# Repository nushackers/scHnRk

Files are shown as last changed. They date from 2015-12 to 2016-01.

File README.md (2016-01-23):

# scHnRk

The scHnRk (pronounced as snark) is a digispark/arduino compatible prototyping board developed for Hack&Roll'16.

The hardware design, firmware and software are derived from Galvant/usb_wrapper-pcb, digispark, micronucleus and arduino. Any derivative from their work is released under the Creative Commons License CC BY 4.0 wherever possible. (I'm no lawyer)

## Hardware

This design is adapted from the venerable DigiSpark.

Here's the lowdown on the stats
- ATTINY85
  - 8KB Flash Memory
  - 512B EEPROM
  - 6 I/O Pins (SPI)
- Acessories
  - 5 WS2812B LEDs
  - 2 CR2032 Battery Holders
  - 2 LEDs (Status, Pwr)
  - USB Wrapper (In some circles its called USB Condom)
  - USB Connector

The scHnRk consists of 2 independent components, separable from one another. The main componenet is a digispark clone which is fully assembled, the smaller component is a partially assembled/ unassembled usb-wrapper-pcb kit. 

## Kits

### Green (unassembled usb-wrapper-pcb)

- Resistor Information for green kits can be inferred from the following  
  - Galvant/usb_wrapper-pcb (Github)
    - Most basic configuration => R7 == 75K Ohm, R9 == 43.2K Ohm, R8 == R10 == 49.9K Ohm
    - R4 == 180 Ohm, LED == LED

### Orange (partially assembled usb-wrapper-pcb)

- Just solder on USB connector and you're set!

## Firmware

A jig will be provided on the day itself for firmware (bootloader) reprogramming using SPI. 

## Software

Feel free to program your arduino anyway you want during the competition using arduino IDE and the "on board" USB port!

## Designed by

```
NUSHackers and Pals

Chang Chu-Ming
Chinmay Pendharkar
Harish Venkatesan
Kenneth Lim
Vishnu Prem
Rahul Gokul
Sayanee Basu
Shanmugam Mpl
Yeo Kheng Meng
Jeremias Wong
```

## Secret Features

One has to be granted WOC REPUS Previleges before one accesses the secret features/puzzle.

There might be prizes for people who crack the puzzle during the hackathon! Maybe we forgot lol?

## Sponsors
 
### Platinum Sponsor
```
Zalora
```

### Gold Sponsors
```
Garena
Palantir
```

### Silver Sponsors
```
Titansoft
Google
Jane Street
Stripe
```

### Bronze Sponsors
```
Zopim
Carousell
NUS School of Computing
```

We thank the sponsors for making this happen.

Also we're looking out for sponsors for the next hackathon! Please contact us at coreteam@nushackers.org!

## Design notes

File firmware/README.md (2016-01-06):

# Firmware

## Hardware Setup

Here's our hardware setup to load the firmware into the ScHnRk.

- Windows Computer
  - AVRISP (USB)
    - AVRISP (SPI)
      - Self made jig
        - ScHnRk SPI interface 

We used microneucleus bootloader for schnrk v0.1 - v0.7

### Archived Setup

Raspberry Pi bit banging seems to fail, so we are using AVRISP instead.

```
Raspberry Pi
- GPIO pin to push NO (Normally Open) button, pulled up to high
- I2C
  - PCF8574 port expander
    -HD44780 LCD Controller
      -*LCD*
- SPI
  - Self made jig
    - ScHnRk SPI interface 
```

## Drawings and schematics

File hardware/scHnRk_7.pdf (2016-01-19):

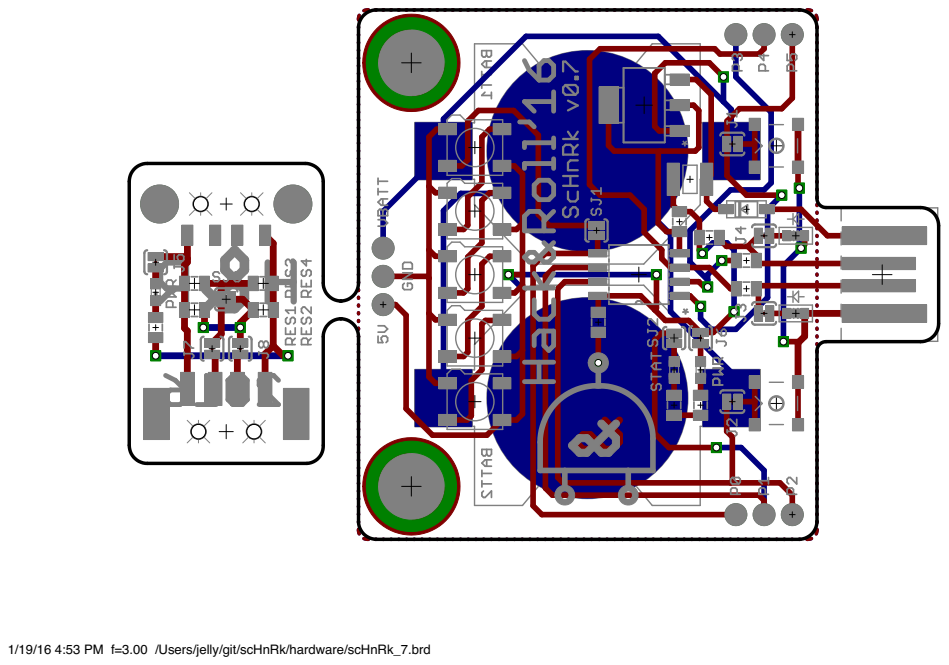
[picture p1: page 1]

1/19/16 4:53 PM f=3.00 /Users/jelly/git/scHnRk/hardware/scHnRk_7.brd

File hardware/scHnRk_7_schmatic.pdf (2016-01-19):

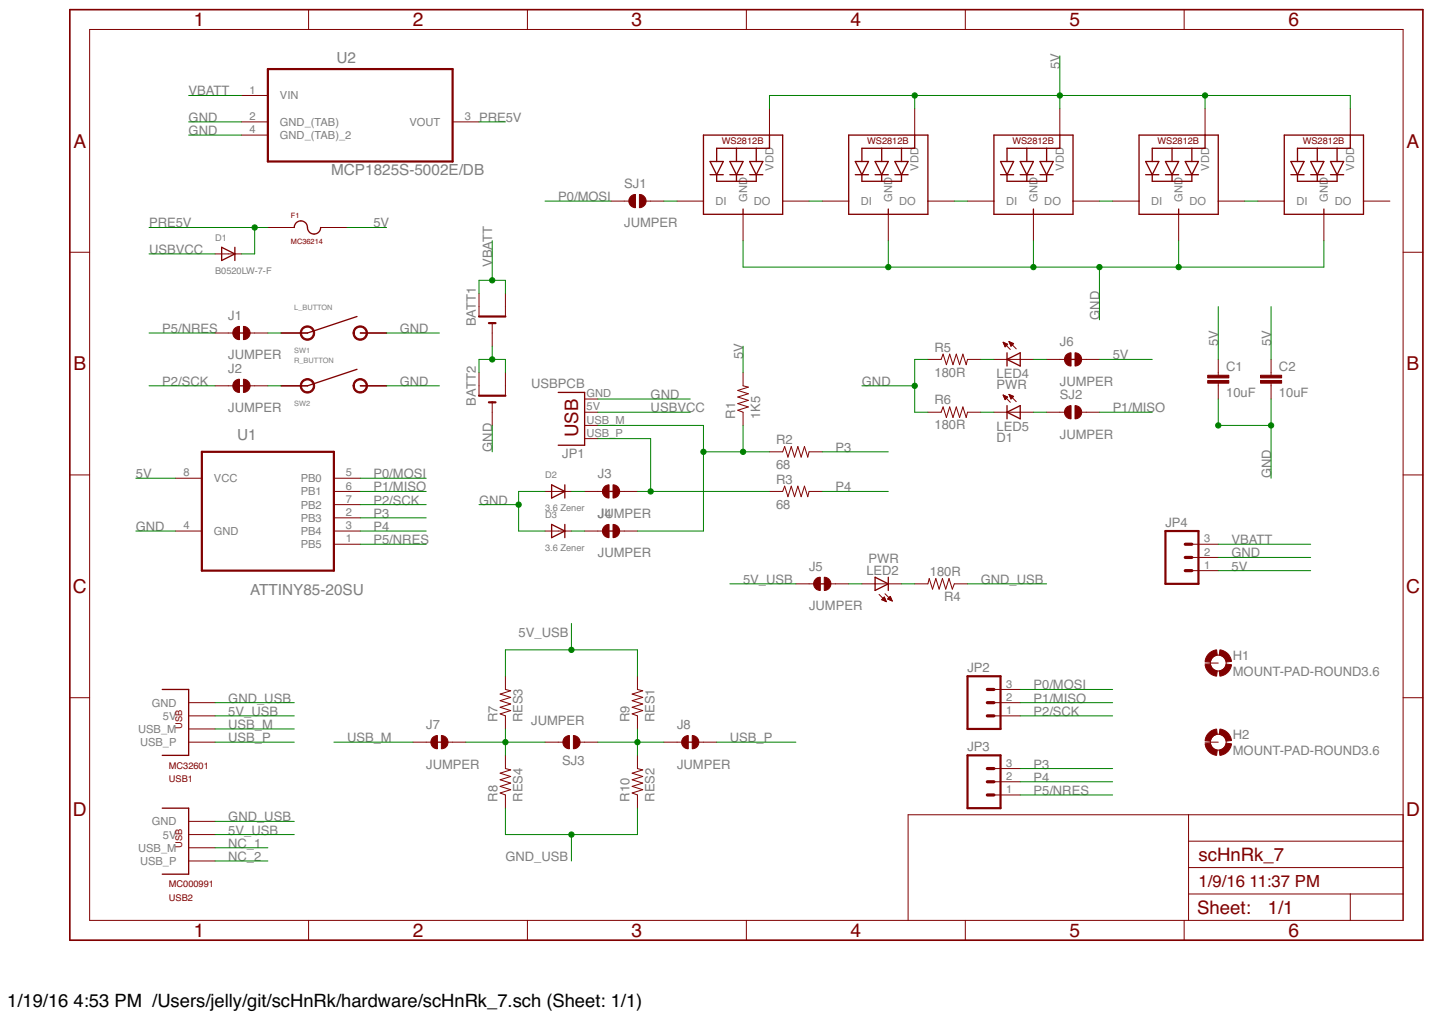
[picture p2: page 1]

1/19/16 4:53 PM /Users/jelly/git/scHnRk/hardware/scHnRk_7.sch (Sheet: 1/1)

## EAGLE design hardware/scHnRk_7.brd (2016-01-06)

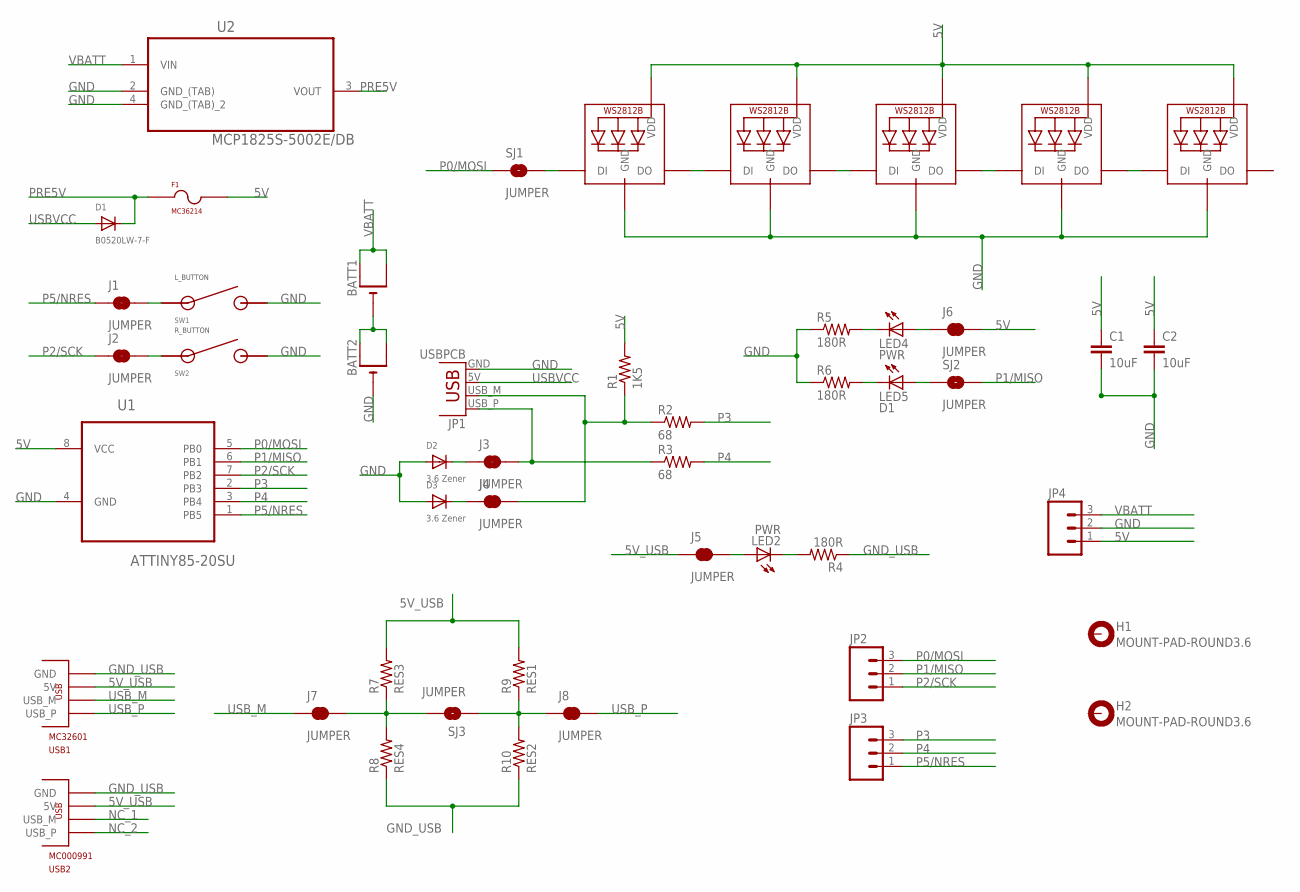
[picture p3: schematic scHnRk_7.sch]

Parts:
BATT1, BATT2: CR2032SMT; CR2032-SMD
C1, C2: 10uF; 0805
D1: B0520LW-7-F; SOD-123
D2, D3: 3.6 Zener; SOD-523
F1: MC36214
H1, H2: MOUNT-PAD-ROUND3.6; 3,6-PAD
J1, J2, J3, J4, J5, J6, J7, J8: JUMPER; PAD-JUMPER-2-NC_BY_TRACE_YES_SILK
JP1: USBPCB; USB-A-PCB
JP2, JP3, JP4: M031X03_NO_SILK; 1X03_NO_SILK
LED1, LED3, LED6, LED7, LED8: WS2812B5050; WS2812B
LED2, LED4: PWR; CHIPLED_0603
LED5: D1; CHIPLED_0603
R1: 1K5; 0805
R2, R3: 68; 0805
R4, R5, R6: 180R; 0805
R7: RES3; 0805
R8: RES4; 0805
R9: RES1; 0805
R10: RES2; 0805
SJ1, SJ2, SJ3: JUMPER; PAD-JUMPER-2-NO_YES_SILK
SW1: L_BUTTON; SKRBAGE010
SW2: R_BUTTON; SKRBAGE010
U1: ATTINY85-20SU; SOIC127P798X216-8N
U2: MCP1825S-5002E/DB; SOT230P700X180-4N
USB1: MC32601
USB2: MC000991

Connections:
5V: C1.1, C2.1, F1.P$2, J6.2, JP4.1, LED1.1-VDD (VDD), LED3.1-VDD (VDD), LED6.1-VDD (VDD), LED7.1-VDD (VDD), LED8.1-VDD (VDD), R1.2, U1.8 (VCC)
5V_USB: J5.1, R7.2, R9.2, USB1.P$2 (5V), USB2.P$4 (5V)
GND: BATT2.-, C1.2, C2.2, D2.A, D3.A, JP1.GND, JP4.2, LED1.3-GND (GND), LED3.3-GND (GND), LED6.3-GND (GND), LED7.3-GND (GND), LED8.3-GND (GND), R5.1, R6.1, SW1.P$2, SW1.P$4, SW2.P$2, SW2.P$4, U1.4 (GND), U2.2 (GND_(TAB)), U2.4 (GND_(TAB)_2)
GND_USB: R4.1, R8.1, R10.1, USB1.P$5 (GND), USB2.P$1 (GND)
unnamed: BATT1.-, BATT2.+$1 (+), BATT2.+$2 (+1)
unnamed: J1.2, SW1.P$1, SW1.P$3
unnamed: LED1.2-DOUT (DO), LED3.4-DIN (DI)
unnamed: LED3.2-DOUT (DO), LED6.4-DIN (DI)
unnamed: LED6.2-DOUT (DO), LED7.4-DIN (DI)
unnamed: LED7.2-DOUT (DO), LED8.4-DIN (DI)
unnamed: J5.2, LED2.A
unnamed: J2.2, SW2.P$1, SW2.P$3
unnamed: D2.K (C), J3.1
unnamed: D3.K (C), J4.1
unnamed: LED1.4-DIN (DI), SJ1.2
unnamed: J4.2, JP1.USB_M (D-), R1.1, R2.1
unnamed: J3.2, JP1.USB_P (D+), R3.1
unnamed: J7.2, R7.1, R8.2, SJ3.2
unnamed: J8.1, R9.1, R10.2, SJ3.1
unnamed: LED2.C, R4.2
unnamed: LED4.C, R5.2
unnamed: LED5.C, R6.2
unnamed: J6.1, LED4.A
unnamed: LED5.A, SJ2.1
NC_1: USB2.P$3 (USB_M)
NC_2: USB2.P$2 (USB_P)
P0/MOSI: JP2.3, SJ1.1, U1.5 (PB0)
P1/MISO: JP2.2, SJ2.2, U1.6 (PB1)
P2/SCK: J2.1, JP2.1, U1.7 (PB2)
P3: JP3.3, R2.2, U1.2 (PB3)
P4: JP3.2, R3.2, U1.3 (PB4)
P5/NRES: J1.1, JP3.1, U1.1 (PB5)
PRE5V: D1.C, F1.P$1, U2.3 (VOUT)
USBVCC: D1.A, JP1.5V (VBUS)
USB_M: J7.1, USB1.P$3 (USB_M)
USB_P: J8.2, USB1.P$4 (USB_P)
VBATT: BATT1.+$1 (+), BATT1.+$2 (+1), JP4.3, U2.1 (VIN)

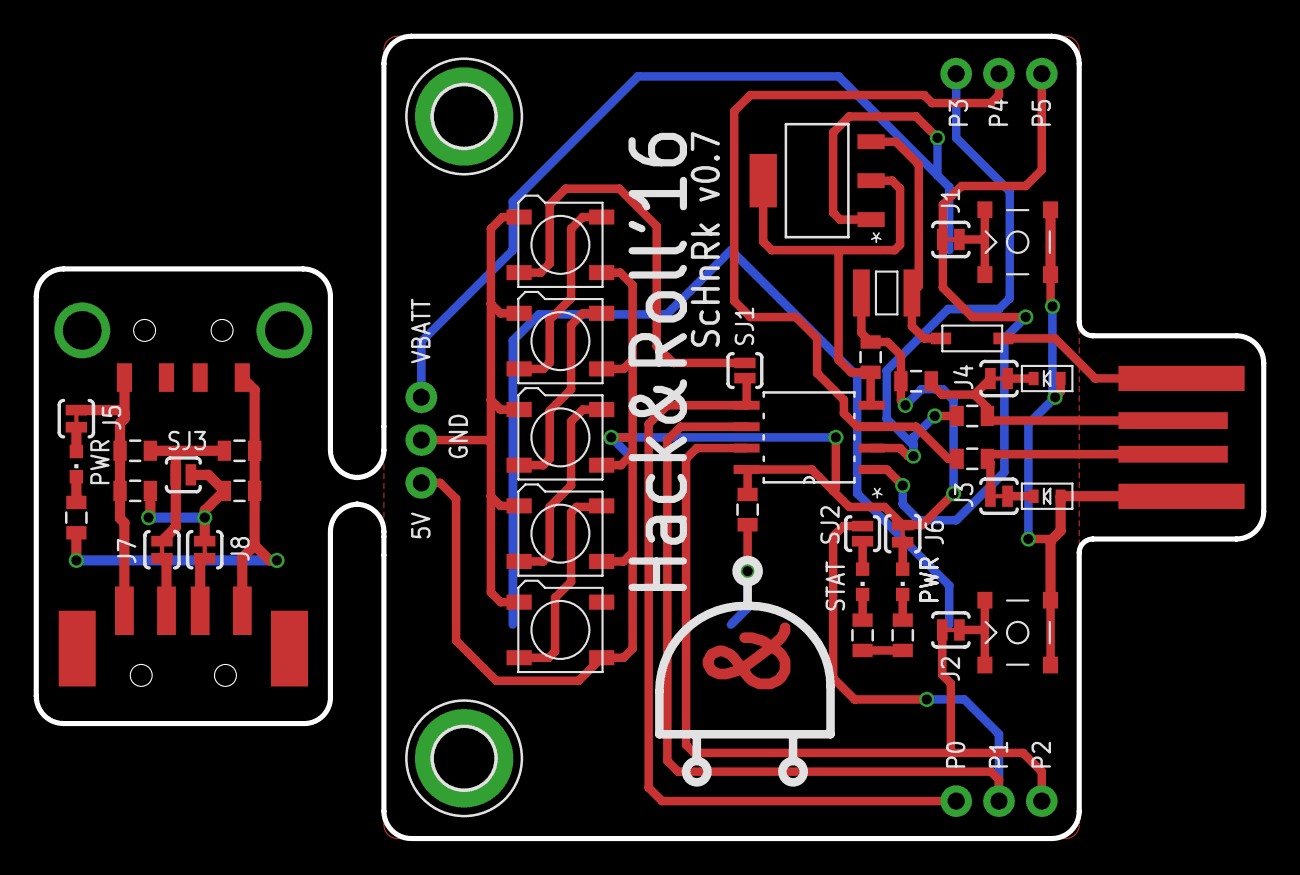
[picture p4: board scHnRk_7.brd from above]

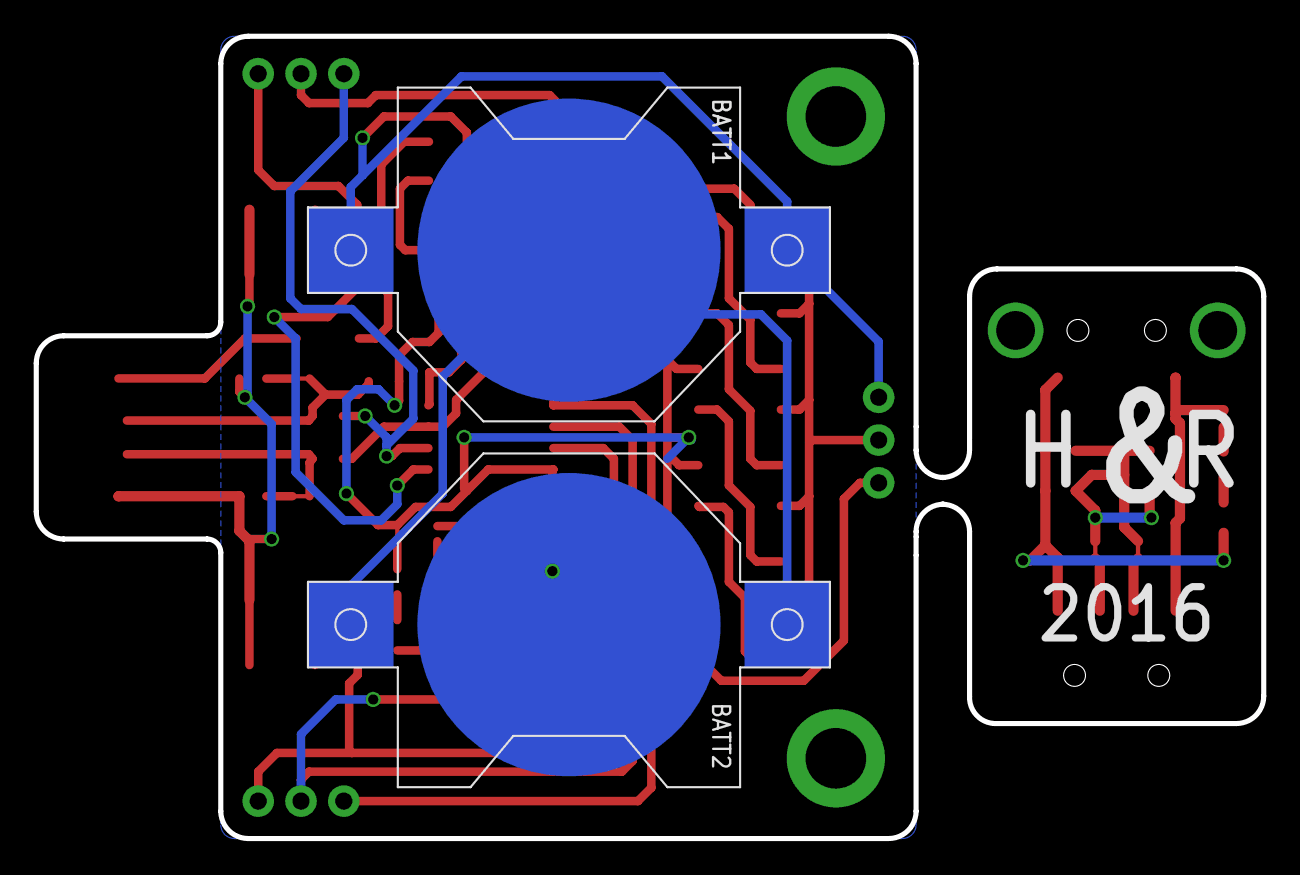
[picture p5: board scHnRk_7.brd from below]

Board: 2 copper layers, 72.9 x 47.6 mm, 49 parts (2 on the bottom side), 35 nets.

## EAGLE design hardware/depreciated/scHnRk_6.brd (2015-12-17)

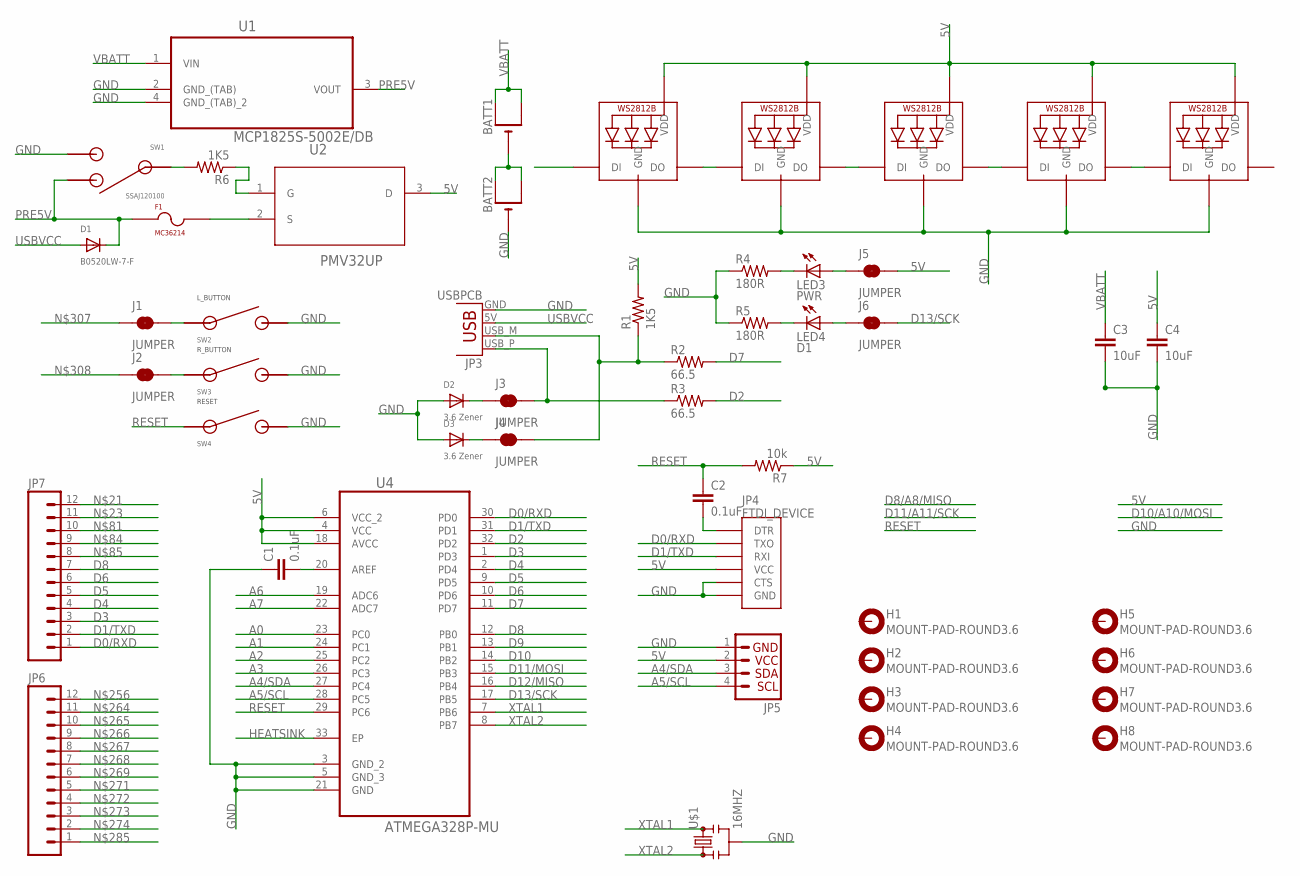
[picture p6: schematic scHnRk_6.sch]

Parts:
BATT1, BATT2: CR2032SMT; CR2032-SMD
C1, C2: 0.1uF; 0805
C3, C4: 10uF; 0805
D1: B0520LW-7-F; SOD-123
D2, D3: 3.6 Zener; SOD-523
F1: MC36214
H1, H2, H3, H4, H5, H6, H7, H8: MOUNT-PAD-ROUND3.6; 3,6-PAD
J1, J2, J3, J4, J5, J6: JUMPER; PAD-JUMPER-2-NC_BY_TRACE_YES_SILK
JP3: USBPCB; USB-A-PCB
JP4: FTDI_DEVICE; FTDI_DEVICE_SIDE
JP5: I2C_STANDARD; 1X04
JP6, JP7: M12PTH; 1X12
LED1, LED2, LED5, LED6, LED7: WS2812B5050; WS2812B
LED3: PWR; CHIPLED_0603
LED4: D1; CHIPLED_0603
R1, R6: 1K5; 0805
R2, R3: 66.5; 0603-RES
R4, R5: 180R; 0805
R7: 10k; 0805
SW1: SSAJ120100
SW2: L_BUTTON; SKRBAGE010
SW3: R_BUTTON; SKRBAGE010
SW4: RESET; SKRBAGE010
U1: MCP1825S-5002E/DB; SOT230P700X180-4N
U2: PMV32UP; SOT95P230X110-3N
U4: ATMEGA328P-MU; QFN50P500X500X100-33N
U$1: 16MHZ; RESONATOR-SMD

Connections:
5V: C4.1, J5.2, JP4.P$4 (VCC), JP5.2, LED1.1-VDD (VDD), LED2.1-VDD (VDD), LED5.1-VDD (VDD), LED6.1-VDD (VDD), LED7.1-VDD (VDD), R1.2, R7.1, U2.3 (D), U4.4 (VCC), U4.6 (VCC_2), U4.18 (AVCC)
A0: U4.23 (PC0)
A1: U4.24 (PC1)
A2: U4.25 (PC2)
A3: U4.26 (PC3)
A4/SDA: JP5.3, U4.27 (PC4)
A5/SCL: JP5.4, U4.28 (PC5)
A6: U4.19 (ADC6)
A7: U4.22 (ADC7)
D0/RXD: JP4.P$2 (TXO), JP7.1, U4.30 (PD0)
D1/TXD: JP4.P$3 (RXI), JP7.2, U4.31 (PD1)
D2: R3.2, U4.32 (PD2)
D3: JP7.3, U4.1 (PD3)
D4: JP7.4, U4.2 (PD4)
D5: JP7.5, U4.9 (PD5)
D6: JP7.6, U4.10 (PD6)
D7: R2.2, U4.11 (PD7)
D8: JP7.7, U4.12 (PB0)
D9: U4.13 (PB1)
D10: U4.14 (PB2)
D11/MOSI: U4.15 (PB3)
D12/MISO: U4.16 (PB4)
D13/SCK: J6.2, U4.17 (PB5)
GND: BATT2.-, C1.1, C3.2, C4.2, D2.A, D3.A, JP3.GND, JP4.P$5 (CTS), JP4.P$6 (GND), JP5.1, LED1.3-GND (GND), LED2.3-GND (GND), LED5.3-GND (GND), LED6.3-GND (GND), LED7.3-GND (GND), R4.1, R5.1, SW1.P$2, SW2.P$2, SW2.P$4, SW3.P$2, SW3.P$4, SW4.P$2, SW4.P$4, U1.2 (GND_(TAB)), U1.4 (GND_(TAB)_2), U4.3 (GND_2), U4.5 (GND_3), U4.21 (GND), U$1.2
HEATSINK: U4.33 (EP)
unnamed: BATT1.-, BATT2.+$1 (+), BATT2.+$2 (+1)
unnamed: J1.2, SW2.P$1, SW2.P$3
unnamed: LED1.2-DOUT (DO), LED2.4-DIN (DI)
unnamed: LED2.2-DOUT (DO), LED5.4-DIN (DI)
unnamed: LED5.2-DOUT (DO), LED6.4-DIN (DI)
unnamed: LED6.2-DOUT (DO), LED7.4-DIN (DI)
unnamed: R6.2, SW1.P$C
unnamed: J2.2, SW3.P$1, SW3.P$3
unnamed: D2.K (C), J3.1
unnamed: D3.K (C), J4.1
unnamed: J4.2, JP3.USB_M (D-), R1.1, R2.1
unnamed: J3.2, JP3.USB_P (D+), R3.1
unnamed: R6.1, U2.1 (G)
unnamed: F1.P$2, U2.2 (S)
unnamed: C2.2, JP4.P$1 (DTR)
unnamed: LED3.C, R4.2
unnamed: LED4.C, R5.2
unnamed: J5.1, LED3.A
unnamed: J6.1, LED4.A
unnamed: C1.2, U4.20 (AREF)
PRE5V: D1.C, F1.P$1, SW1.P$1, U1.3 (VOUT)
RESET: C2.1, R7.2, SW4.P$1, SW4.P$3, U4.29 (PC6)
USBVCC: D1.A, JP3.5V (VBUS)
VBATT: BATT1.+$1 (+), BATT1.+$2 (+1), C3.1, U1.1 (VIN)
XTAL1: U4.7 (PB6), U$1.3
XTAL2: U4.8 (PB7), U$1.1

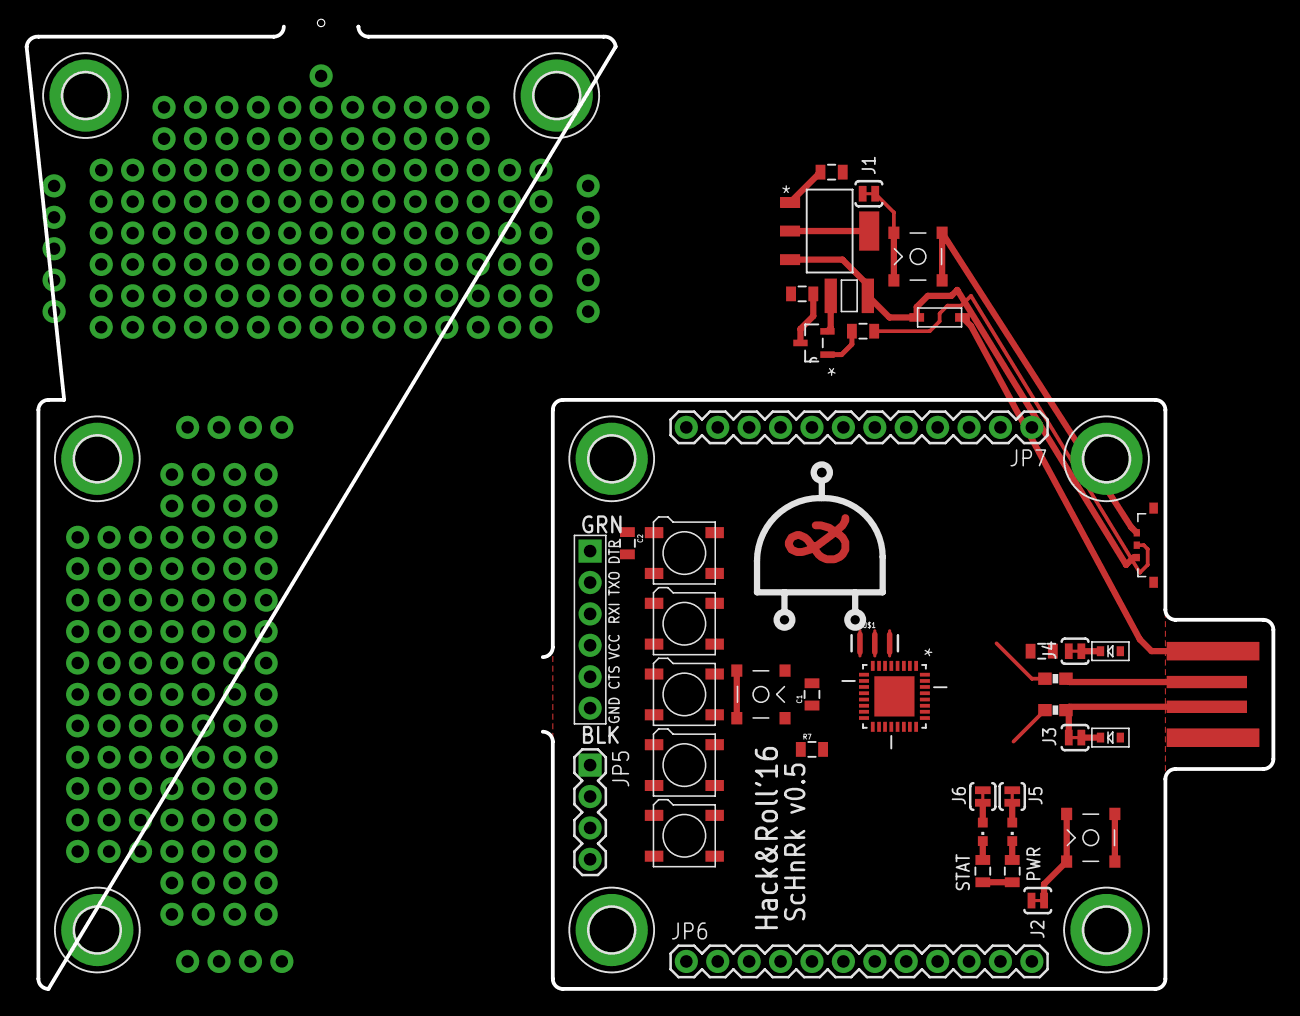
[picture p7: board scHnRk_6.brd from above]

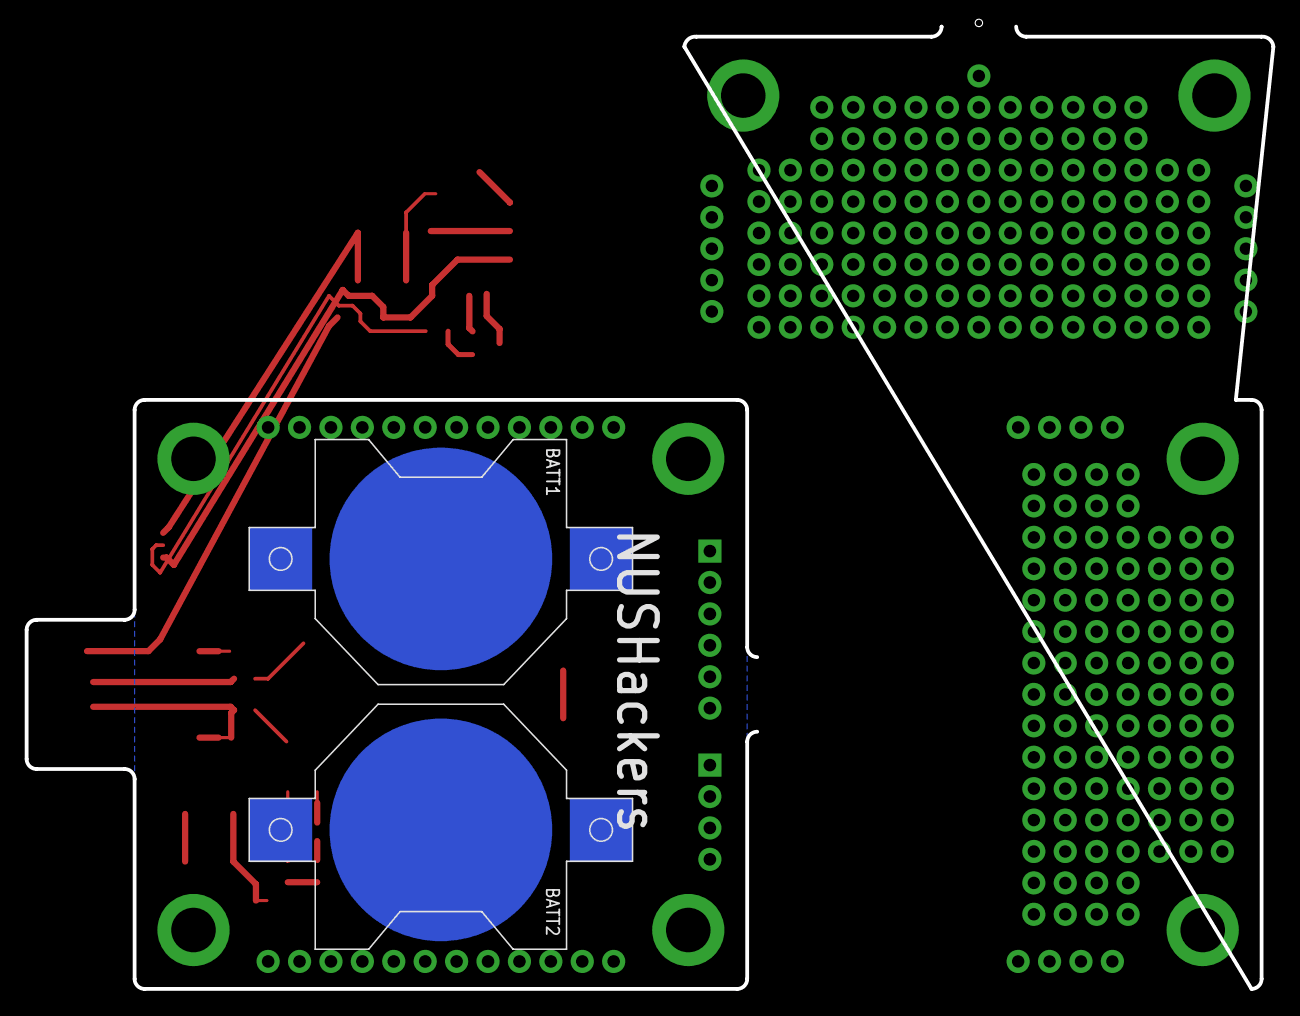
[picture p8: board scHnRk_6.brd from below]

Board: 2 copper layers, 100.8 x 77.8 mm, 51 parts (2 on the bottom side), 40 nets.

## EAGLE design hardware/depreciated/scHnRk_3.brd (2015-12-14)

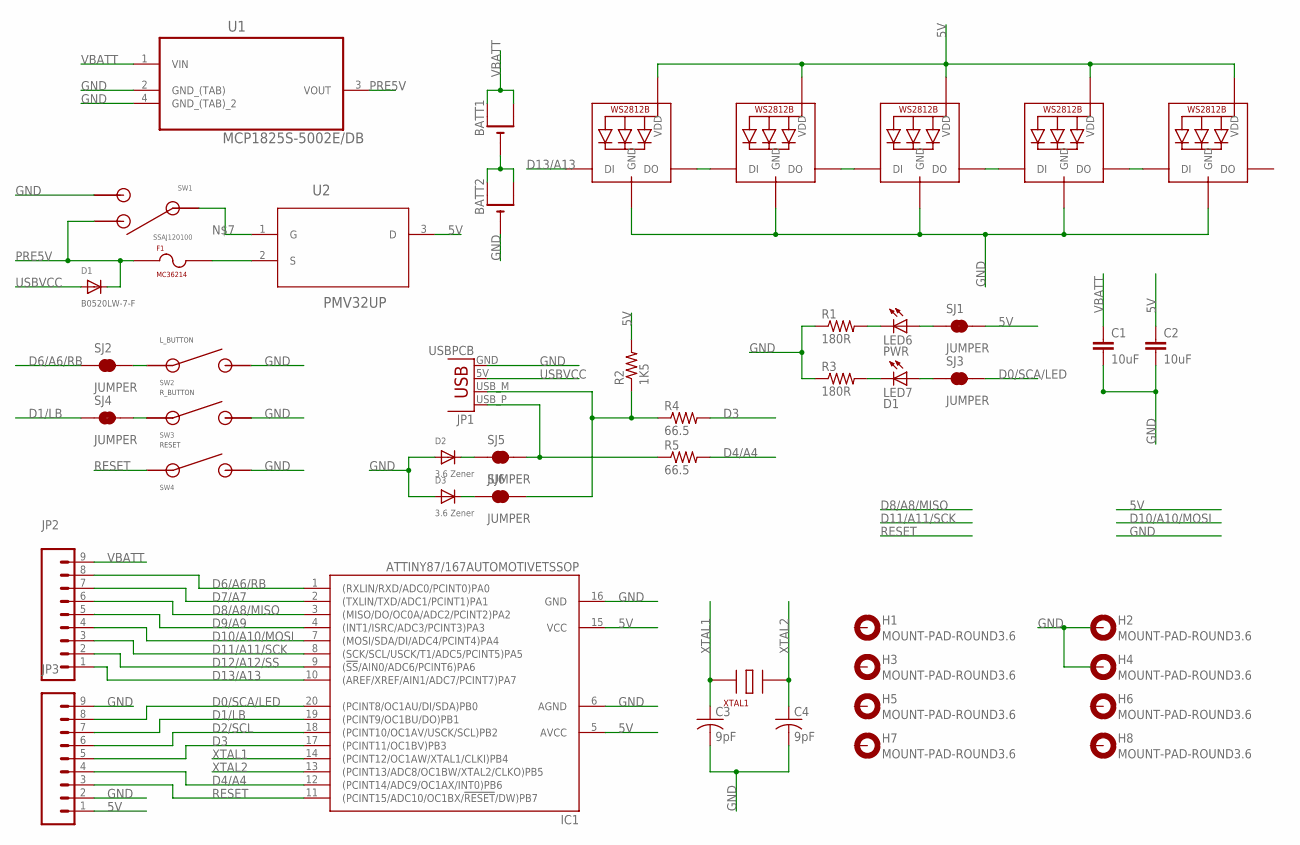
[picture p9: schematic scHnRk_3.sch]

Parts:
BATT1, BATT2: CR2032SMT; CR2032-SMD
C1, C2: 10uF; 0805
C3, C4: 9pF; C0603K
D1: B0520LW-7-F; SOD-123
D2, D3: 3.6 Zener; SOD-523
F1: MC36214
H1, H2, H3, H4, H5, H6, H7, H8: MOUNT-PAD-ROUND3.6; 3,6-PAD
IC1: ATTINY87/167AUTOMOTIVETSSOP; TSSOP20
JP1: USBPCB; USB-A-PCB
JP2, JP3: M09; 1X09
LED1, LED2, LED3, LED4, LED5: WS2812B5050; WS2812B
LED6: PWR; CHIPLED_0603
LED7: D1; CHIPLED_0603
R1, R3: 180R; R0603
R2: 1K5; R0603
R4, R5: 66.5; R0603
SJ1, SJ2, SJ3, SJ4, SJ5, SJ6: JUMPER; PAD-JUMPER-2-NC_BY_TRACE_YES_SILK
SW1: SSAJ120100
SW2: L_BUTTON; SKRBAGE010
SW3: R_BUTTON; SKRBAGE010
SW4: RESET; SKRBAGE010
U1: MCP1825S-5002E/DB; SOT230P700X180-4N
U2: PMV32UP; SOT95P230X110-3N
XTAL1: 16MHZ-2467444

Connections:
5V: C2.1, IC1.5 (AVCC), IC1.15 (VCC), JP3.1, LED1.1-VDD (VDD), LED2.1-VDD (VDD), LED3.1-VDD (VDD), LED4.1-VDD (VDD), LED5.1-VDD (VDD), R2.2, SJ1.2, U2.3 (D)
D0/SCA/LED: IC1.20 ((PCINT8/OC1AU/DI/SDA)PB0), JP3.8, SJ3.2
D1/LB: IC1.19 ((PCINT9/OC1BU/DO)PB1), JP3.7, SJ4.1
D2/SCL: IC1.18 ((PCINT10/OC1AV/USCK/SCL)PB2), JP3.6
D3: IC1.17 ((PCINT11/OC1BV)PB3), JP3.5, R4.2
D4/A4: IC1.12 ((PCINT14/ADC9/OC1AX/INT0)PB6), JP3.4, R5.2
D6/A6/RB: IC1.1 ((RXLIN/RXD/ADC0/PCINT0)PA0), JP2.8, SJ2.1
D7/A7: IC1.2 ((TXLIN/TXD/ADC1/PCINT1)PA1), JP2.7
D8/A8/MISO: IC1.3 ((MISO/DO/OC0A/ADC2/PCINT2)PA2), JP2.6
D9/A9: IC1.4 ((INT1/ISRC/ADC3/PCINT3)PA3), JP2.5
D10/A10/MOSI: IC1.7 ((MOSI/SDA/DI/ADC4/PCINT4)PA4), JP2.4
D11/A11/SCK: IC1.8 ((SCK/SCL/USCK/T1/ADC5/PCINT5)PA5), JP2.3
D12/A12/SS: IC1.9 ((!SS!/AIN0/ADC6/PCINT6)PA6), JP2.2
D13/A13: IC1.10 ((AREF/XREF/AIN1/ADC7/PCINT7)PA7), JP2.1, LED1.4-DIN (DI)
GND: BATT2.-, C1.2, C2.2, C3.2, C4.2, D2.A, D3.A, H2.B3,6, H4.B3,6, IC1.6 (AGND), IC1.16 (GND), JP1.GND, JP3.2, JP3.9, LED1.3-GND (GND), LED2.3-GND (GND), LED3.3-GND (GND), LED4.3-GND (GND), LED5.3-GND (GND), R1.1, R3.1, SW1.P$2, SW2.P$2, SW2.P$4, SW3.P$2, SW3.P$4, SW4.P$2, SW4.P$4, U1.2 (GND_(TAB)), U1.4 (GND_(TAB)_2)
unnamed: BATT1.-, BATT2.+$1 (+), BATT2.+$2 (+1)
unnamed: SJ2.2, SW2.P$1, SW2.P$3
unnamed: LED1.2-DOUT (DO), LED2.4-DIN (DI)
unnamed: LED2.2-DOUT (DO), LED3.4-DIN (DI)
unnamed: LED3.2-DOUT (DO), LED4.4-DIN (DI)
unnamed: LED4.2-DOUT (DO), LED5.4-DIN (DI)
unnamed: SW1.P$C, U2.1 (G)
unnamed: SJ4.2, SW3.P$1, SW3.P$3
unnamed: D2.K (C), SJ5.1
unnamed: D3.K (C), SJ6.1
unnamed: JP1.USB_M (D-), R2.1, R4.1, SJ6.2
unnamed: JP1.USB_P (D+), R5.1, SJ5.2
unnamed: F1.P$2, U2.2 (S)
unnamed: LED6.C, R1.2
unnamed: LED7.C, R3.2
unnamed: LED6.A, SJ1.1
unnamed: LED7.A, SJ3.1
PRE5V: D1.C, F1.P$1, SW1.P$1, U1.3 (VOUT)
RESET: IC1.11 ((PCINT15/ADC10/OC1BX/!RESET!/DW)PB7), JP3.3, SW4.P$1, SW4.P$3
USBVCC: D1.A, JP1.5V (VBUS)
VBATT: BATT1.+$1 (+), BATT1.+$2 (+1), C1.1, JP2.9, U1.1 (VIN)
XTAL1: C3.1, IC1.14 ((PCINT12/OC1AW/XTAL1/CLKI)PB4), XTAL1.P$1
XTAL2: C4.1, IC1.13 ((PCINT13/ADC8/OC1BW/XTAL2/CLKO)PB5), XTAL1.P$3

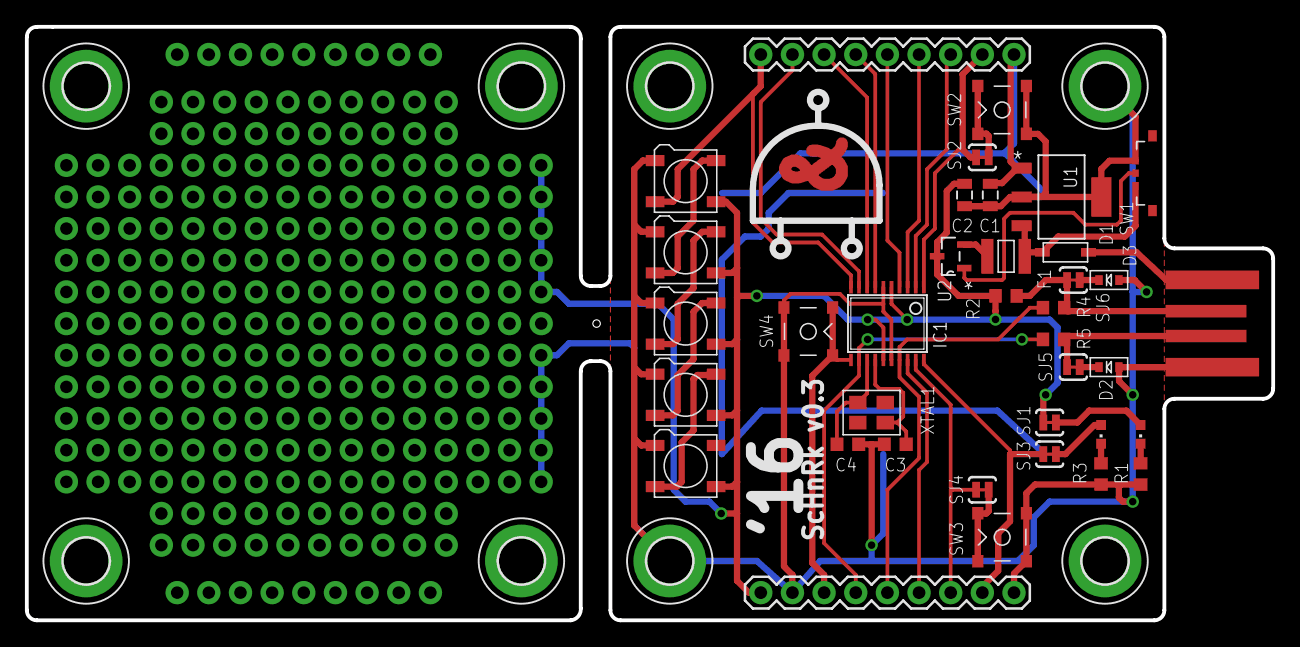
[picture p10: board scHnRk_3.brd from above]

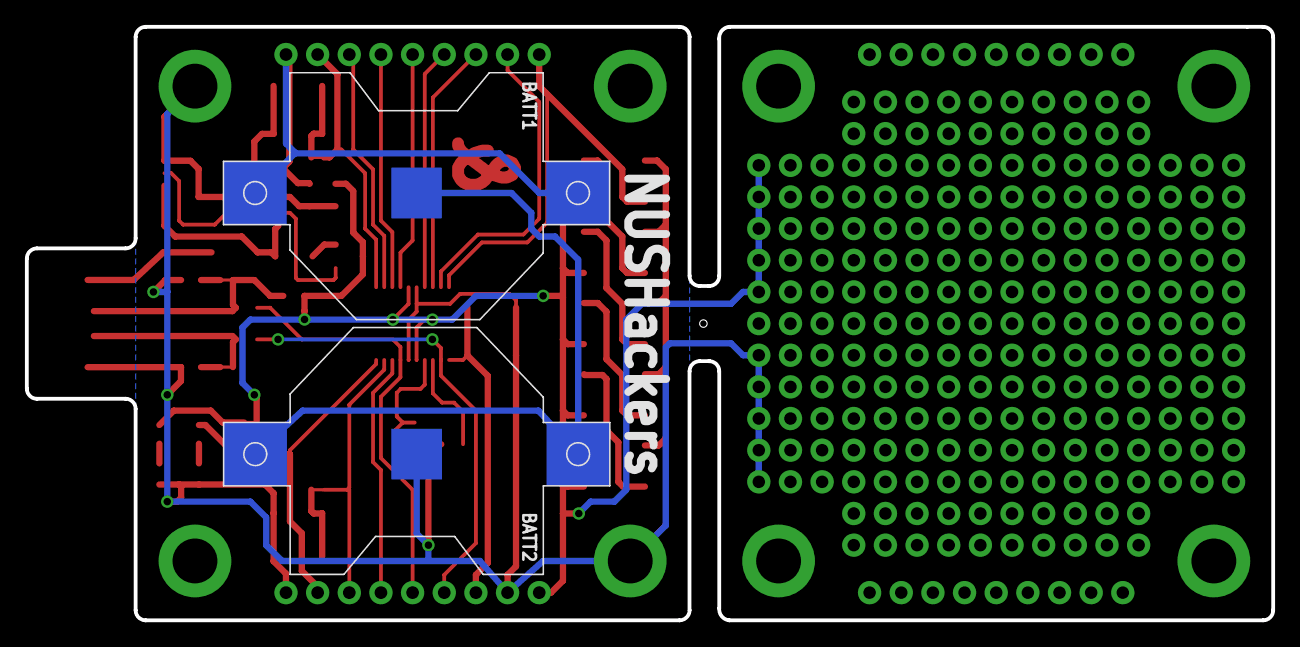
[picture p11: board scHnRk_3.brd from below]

Board: 2 copper layers, 100.0 x 47.6 mm, 47 parts (2 on the bottom side), 38 nets.

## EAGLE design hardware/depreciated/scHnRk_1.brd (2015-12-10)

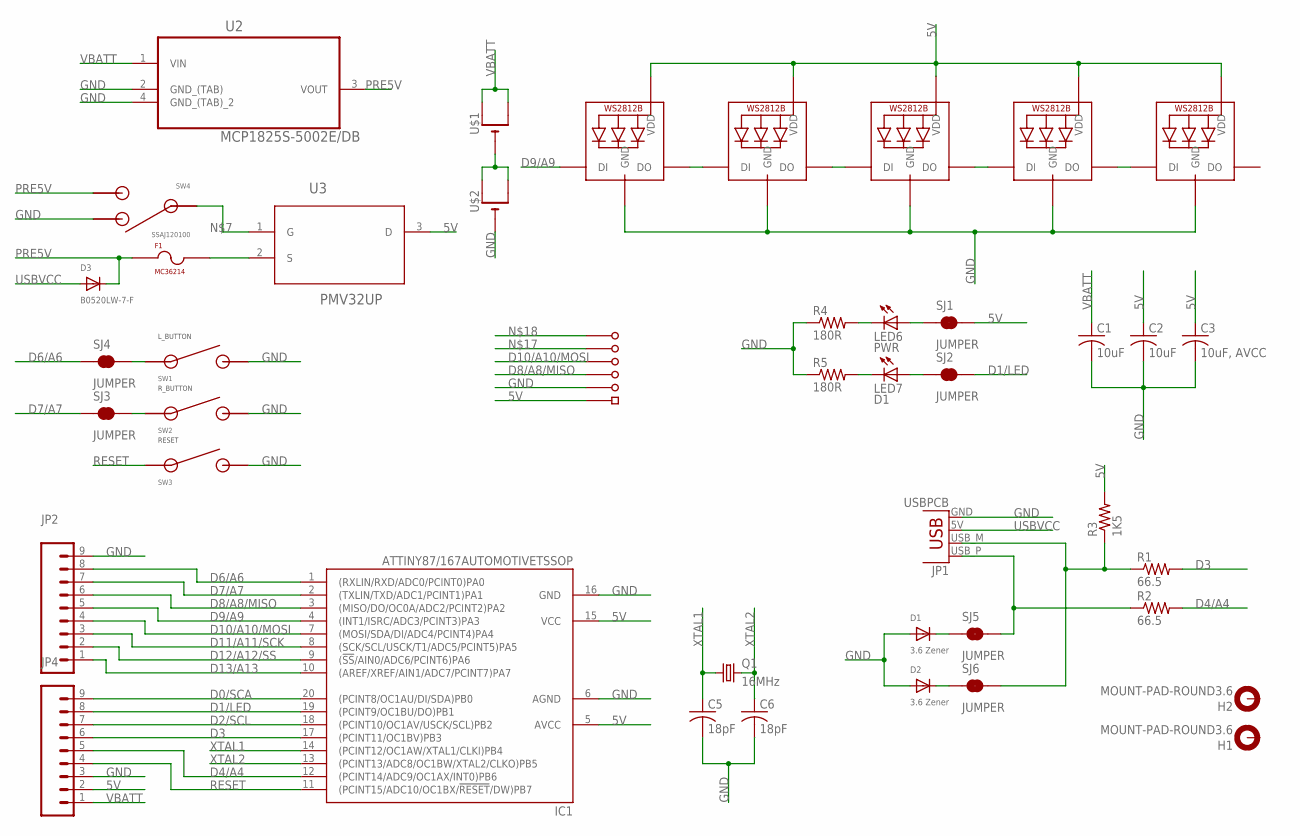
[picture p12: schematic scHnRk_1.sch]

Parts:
C1, C2: 10uF; C1206K
C3: 10uF, AVCC; C1206K
C5, C6: 18pF; C0603K
D1, D2: 3.6 Zener; SOD-523
D3: B0520LW-7-F; SOD-123
F1: MC36214
H1, H2: MOUNT-PAD-ROUND3.6; 3,6-PAD
IC1: ATTINY87/167AUTOMOTIVETSSOP; TSSOP20
JP1: USBPCB; USB-A-PCB
JP2, JP4: M09; 1X09
LED1, LED2, LED3, LED4, LED5: WS2812B5050; WS2812B
LED6: PWR; CHIPLED_0603
LED7: D1; CHIPLED_0603
Q1: 16MHz; HC49UP
R1, R2: 66.5; R0603
R3: 1K5; R0603
R4, R5: 180R; R0603
SJ1, SJ2, SJ3, SJ4, SJ5, SJ6: JUMPER; PAD-JUMPER-2-NC_BY_TRACE_YES_SILK
SW1: L_BUTTON; SKRBAGE010
SW2: R_BUTTON; SKRBAGE010
SW3: RESET; SKRBAGE010
SW4: SSAJ120100
TP1, TP3, TP4, TP5, TP6: TP-R
TP2: TP-S; TP_S
U2: MCP1825S-5002E/DB; SOT230P700X180-4N
U3: PMV32UP; SOT95P230X110-3N
U$1, U$2: CR2032SMT; CR2032-SMD

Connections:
5V: C2.1, C3.1, IC1.5 (AVCC), IC1.15 (VCC), JP4.2, LED1.1-VDD (VDD), LED2.1-VDD (VDD), LED3.1-VDD (VDD), LED4.1-VDD (VDD), LED5.1-VDD (VDD), R3.2, SJ1.2, TP2.P$1, U3.3 (D)
D0/SCA: IC1.20 ((PCINT8/OC1AU/DI/SDA)PB0), JP4.9
D1/LED: IC1.19 ((PCINT9/OC1BU/DO)PB1), JP4.8, SJ2.2
D2/SCL: IC1.18 ((PCINT10/OC1AV/USCK/SCL)PB2), JP4.7
D3: IC1.17 ((PCINT11/OC1BV)PB3), JP4.6, R1.2
D4/A4: IC1.12 ((PCINT14/ADC9/OC1AX/INT0)PB6), JP4.5, R2.2
D6/A6: IC1.1 ((RXLIN/RXD/ADC0/PCINT0)PA0), JP2.8, SJ4.1
D7/A7: IC1.2 ((TXLIN/TXD/ADC1/PCINT1)PA1), JP2.7, SJ3.1
D8/A8/MISO: IC1.3 ((MISO/DO/OC0A/ADC2/PCINT2)PA2), JP2.6, TP3.P$1
D9/A9: IC1.4 ((INT1/ISRC/ADC3/PCINT3)PA3), JP2.5, LED1.4-DIN (DI)
D10/A10/MOSI: IC1.7 ((MOSI/SDA/DI/ADC4/PCINT4)PA4), JP2.4, TP4.P$1
D11/A11/SCK: IC1.8 ((SCK/SCL/USCK/T1/ADC5/PCINT5)PA5), JP2.3
D12/A12/SS: IC1.9 ((!SS!/AIN0/ADC6/PCINT6)PA6), JP2.2
D13/A13: IC1.10 ((AREF/XREF/AIN1/ADC7/PCINT7)PA7), JP2.1
GND: C1.2, C2.2, C3.2, C5.2, C6.2, D1.A, D2.A, IC1.6 (AGND), IC1.16 (GND), JP1.GND, JP2.9, JP4.3, LED1.3-GND (GND), LED2.3-GND (GND), LED3.3-GND (GND), LED4.3-GND (GND), LED5.3-GND (GND), R4.1, R5.1, SW1.P$2, SW1.P$4, SW2.P$2, SW2.P$4, SW3.P$2, SW3.P$4, SW4.P$1, TP1.P$1, U2.2 (GND_(TAB)), U2.4 (GND_(TAB)_2), U$2.-
unnamed: U$1.-, U$2.+$1 (+), U$2.+$2 (+1)
unnamed: SJ4.2, SW1.P$1, SW1.P$3
unnamed: LED1.2-DOUT (DO), LED2.4-DIN (DI)
unnamed: LED2.2-DOUT (DO), LED3.4-DIN (DI)
unnamed: LED3.2-DOUT (DO), LED4.4-DIN (DI)
unnamed: LED4.2-DOUT (DO), LED5.4-DIN (DI)
unnamed: SW4.P$C, U3.1 (G)
unnamed: SJ3.2, SW2.P$1, SW2.P$3
unnamed: D1.K (C), SJ5.1
unnamed: D2.K (C), SJ6.1
unnamed: JP1.USB_M (D-), R1.1, R3.1, SJ6.2
unnamed: JP1.USB_P (D+), R2.1, SJ5.2
unnamed: F1.P$2, U3.2 (S)
unnamed: LED6.C, R4.2
unnamed: LED7.C, R5.2
unnamed: LED6.A, SJ1.1
unnamed: LED7.A, SJ2.1
PRE5V: D3.C, F1.P$1, SW4.P$2, U2.3 (VOUT)
RESET: IC1.11 ((PCINT15/ADC10/OC1BX/!RESET!/DW)PB7), JP4.4, SW3.P$1, SW3.P$3
USBVCC: D3.A, JP1.5V (VBUS)
VBATT: C1.1, JP4.1, U2.1 (VIN), U$1.+$1 (+), U$1.+$2 (+1)
XTAL1: C5.1, IC1.14 ((PCINT12/OC1AW/XTAL1/CLKI)PB4), Q1.1
XTAL2: C6.1, IC1.13 ((PCINT13/ADC8/OC1BW/XTAL2/CLKO)PB5), Q1.2

Board: 2 copper layers, 48 parts (2 on the bottom side), 38 nets, no tracks yet.

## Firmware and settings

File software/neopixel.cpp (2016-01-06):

/*
* This is an adaptation from AdaFruit's NeoPixel Library
* Enjoy!
*/

#include <Adafruit_NeoPixel.h>

#define BUTTON_PIN   2    // Digital IO pin connected to the button.  This will be
                          // driven with a pull-up resistor so the switch should
                          // pull the pin to ground momentarily.  On a high -> low
                          // transition the button press logic will execute.

#define PIXEL_PIN    6    // Digital IO pin connected to the NeoPixels.

#define PIXEL_COUNT 5

// Parameter 1 = number of pixels in strip,  neopixel stick has 8
// Parameter 2 = pin number (most are valid)
// Parameter 3 = pixel type flags, add together as needed:
//   NEO_RGB     Pixels are wired for RGB bitstream
//   NEO_GRB     Pixels are wired for GRB bitstream, correct for neopixel stick
//   NEO_KHZ400  400 KHz bitstream (e.g. FLORA pixels)
//   NEO_KHZ800  800 KHz bitstream (e.g. High Density LED strip), correct for neopixel stick
Adafruit_NeoPixel strip = Adafruit_NeoPixel(PIXEL_COUNT, PIXEL_PIN, NEO_GRB + NEO_KHZ800);

bool oldState = HIGH;
int showType = 0;

void setup() {
  //Enable button, pull up
  pinMode(BUTTON_PIN, INPUT);
  digitalWrite(BUTTON_PIN, HIGH);
  
  strip.begin();
  strip.show(); // Initialize all pixels to 'off'
}

void loop() {
  // Get current button state.
  bool newState = digitalRead(BUTTON_PIN);

  // Check if state changed from high to low (button press).
  if (newState == LOW && oldState == HIGH) {
    // Short delay to debounce button.
    delay(20);
    // Check if button is still low after debounce.
    newState = digitalRead(BUTTON_PIN);
    if (newState == LOW) {
      showType++;
      if (showType > 9)
        showType=0;
      startShow(showType);
    }
  }

  // Set the last button state to the old state.
  oldState = newState;
}

void startShow(int i) {
  switch(i){
    case 0: colorWipe(strip.Color(0, 0, 0), 50);    // Black/off
            break;
    case 1: colorWipe(strip.Color(255, 0, 0), 50);  // Red
            break;
    case 2: colorWipe(strip.Color(0, 255, 0), 50);  // Green
            break;
    case 3: colorWipe(strip.Color(0, 0, 255), 50);  // Blue
            break;
    case 4: theaterChase(strip.Color(127, 127, 127), 50); // White
            break;
    case 5: theaterChase(strip.Color(127,   0,   0), 50); // Red
            break;
    case 6: theaterChase(strip.Color(  0,   0, 127), 50); // Blue
            break;
    case 7: rainbow(20);
            break;
    case 8: rainbowCycle(20);
            break;
    case 9: theaterChaseRainbow(50);
            break;
  }
}

// Fill the dots one after the other with a color
void colorWipe(uint32_t c, uint8_t wait) {
  for(uint16_t i=0; i<strip.numPixels(); i++) {
    strip.setPixelColor(i, c);
    strip.show();
    delay(wait);
  }
}

void rainbow(uint8_t wait) {
  uint16_t i, j;

  for(j=0; j<256; j++) {
    for(i=0; i<strip.numPixels(); i++) {
      strip.setPixelColor(i, Wheel((i+j) & 255));
    }
    strip.show();
    delay(wait);
  }
}

// Slightly different, this makes the rainbow equally distributed throughout
void rainbowCycle(uint8_t wait) {
  uint16_t i, j;

  for(j=0; j<256*5; j++) { // 5 cycles of all colors on wheel
    for(i=0; i< strip.numPixels(); i++) {
      strip.setPixelColor(i, Wheel(((i * 256 / strip.numPixels()) + j) & 255));
    }
    strip.show();
    delay(wait);
  }
}

//Theatre-style crawling lights.
void theaterChase(uint32_t c, uint8_t wait) {
  for (int j=0; j<10; j++) {  //do 10 cycles of chasing
    for (int q=0; q < 3; q++) {
      for (int i=0; i < strip.numPixels(); i=i+3) {
        strip.setPixelColor(i+q, c);    //turn every third pixel on
      }
      strip.show();

      delay(wait);

      for (int i=0; i < strip.numPixels(); i=i+3) {
        strip.setPixelColor(i+q, 0);        //turn every third pixel off
      }
    }
  }
}

//Theatre-style crawling lights with rainbow effect
void theaterChaseRainbow(uint8_t wait) {
  for (int j=0; j < 256; j++) {     // cycle all 256 colors in the wheel
    for (int q=0; q < 3; q++) {
      for (int i=0; i < strip.numPixels(); i=i+3) {
        strip.setPixelColor(i+q, Wheel( (i+j) % 255));    //turn every third pixel on
      }
      strip.show();

      delay(wait);

      for (int i=0; i < strip.numPixels(); i=i+3) {
        strip.setPixelColor(i+q, 0);        //turn every third pixel off
      }
    }
  }
}

// Input a value 0 to 255 to get a color value.
// The colours are a transition r - g - b - back to r.
uint32_t Wheel(byte WheelPos) {
  WheelPos = 255 - WheelPos;
  if(WheelPos < 85) {
    return strip.Color(255 - WheelPos * 3, 0, WheelPos * 3);
  }
  if(WheelPos < 170) {
    WheelPos -= 85;
    return strip.Color(0, WheelPos * 3, 255 - WheelPos * 3);
  }
  WheelPos -= 170;
  return strip.Color(WheelPos * 3, 255 - WheelPos * 3, 0);
}

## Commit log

2015-12-10 Init Commit
    [scHnRk.brd, scHnRk.sch, scHnRk_2.brd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]
2015-12-11 schnrk v0.2
    [scHnRk_3.brd, scHnRk_3.sch]
2015-12-14 added new revisions
    [scHnRk_3.brd, scHnRk_4.brd, scHnRk_4.sch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]
2015-12-15 updated to version 5, starting on version 6, moved buttons to edge, add resistor to gate of pwr mosfet
    [scHnRk_6.brd, scHnRk_6.sch]
2015-12-17 added skeletons, transiting to atmega328p-mu
    [scHnRk_1.brd, scHnRk_1.sch, scHnRk_2.brd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]
2016-01-06 updated board, sent to board house
    [scHnRk_6.brd, scHnRk_6.sch, scHnRk_6b.brd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]

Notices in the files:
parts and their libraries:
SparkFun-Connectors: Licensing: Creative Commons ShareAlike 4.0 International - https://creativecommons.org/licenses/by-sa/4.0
